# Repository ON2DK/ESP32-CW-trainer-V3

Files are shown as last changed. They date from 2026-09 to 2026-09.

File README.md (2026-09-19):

# ESP32 CW Trainer V3

Standalone ESP32-based CW/Morse trainer PCB for paddle and straight-key practice.

## V3 hardware revision

V3 standardizes the external connectors on real PCB-mounted parts instead of generic connector placeholders:

- **J4 DC input:** GCT DCJ200-10-A horizontal THT barrel jack
- **J10 Paddle:** CUI/Same Sky SJ1-3533NG 3.5 mm TRS jack
- **J11 Audio/headphone:** CUI/Same Sky SJ1-3533NG 3.5 mm TRS jack
- **J14 Straight Key:** CUI/Same Sky SJ1-3533NG 3.5 mm TRS jack

### Jack wiring

| Connector | Tip | Ring | Sleeve |
|---|---|---|---|
| J10 Paddle | DIT | DAH | GND |
| J11 Audio | Audio via 100 ohm | Audio via 100 ohm | GND |
| J14 Straight Key | STRAIGHT_KEY | Not connected | GND |

J4 uses pin 1 for the DC input to F1, pin 2 for GND, and pin 3 (internal switch contact) is intentionally unused.

## Main hardware

- ESP32-WROOM-32 / 38-pin DevKit footprint
- TFT interface
- Paddle input
- Straight-key input
- Rotary encoder with push switch
- LM386 audio amplifier
- Buzzer
- Volume control
- 12 V external input
- 500 mA resettable fuse
- TRACO TSR 1-2450 5 V regulator

## Design status

As of **19 September 2026**:

- KiCad: **10.0.4**
- ERC: **0 errors, 0 warnings**
- DRC: **0 violations**
- Unconnected PCB items: **0**
- Schematic parity problems: **0**
- Gerber production set regenerated after the V3 connector changes
- Hardware assembly/testing: **pending**

Two intentional ERC exceptions remain documented in the project: the project-specific ESP32 symbol/library difference and the GPIO34 input-only ADC check.

## Production files

The clean all-THT Gerber package contains:

- F.Cu / B.Cu
- F.Mask / B.Mask
- F.Silkscreen / B.Silkscreen
- Edge.Cuts
- PTH drill
- NPTH drill
- .gbrjob

Paste layers are not required for this THT board.

## Recommended repository files

- KiCad schematic (`.kicad_sch`)
- KiCad PCB (`.kicad_pcb`)
- KiCad project (`.kicad_pro`)
- Gerber ZIP
- Arduino firmware (`.ino`)
- Project logbook with BOM and photos
- PCB / schematic / 3D images

## Notes

Before ordering, inspect the final Gerbers in the PCB manufacturer's viewer, especially J4, J10, J11, J14, mounting holes and Edge.Cuts.

This project is currently electrically/design-rule checked, but the V3 hardware has not yet been validated on an assembled PCB.

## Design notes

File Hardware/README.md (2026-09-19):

# Hardware

Plaats hier de KiCad 10.0.4 projectbestanden van de ESP32 CW Trainer V3 (`.kicad_pro`, `.kicad_sch`, `.kicad_pcb`).

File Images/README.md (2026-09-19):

# Images

Afbeeldingen van schema, PCB, 3D-weergave en de later opgebouwde hardware.

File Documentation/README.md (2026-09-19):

# Documentation

Projectdocumentatie voor de ESP32 CW Trainer V3, waaronder het projectlogboek met BOM en foto's.

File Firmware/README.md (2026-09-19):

# Firmware

Plaats hier de Arduino IDE firmware (`.ino`) voor de ESP32 CW Trainer V3.

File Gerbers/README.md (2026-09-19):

# Gerbers

Plaats hier de definitieve productie-GERBER ZIP van de ESP32 CW Trainer V3.

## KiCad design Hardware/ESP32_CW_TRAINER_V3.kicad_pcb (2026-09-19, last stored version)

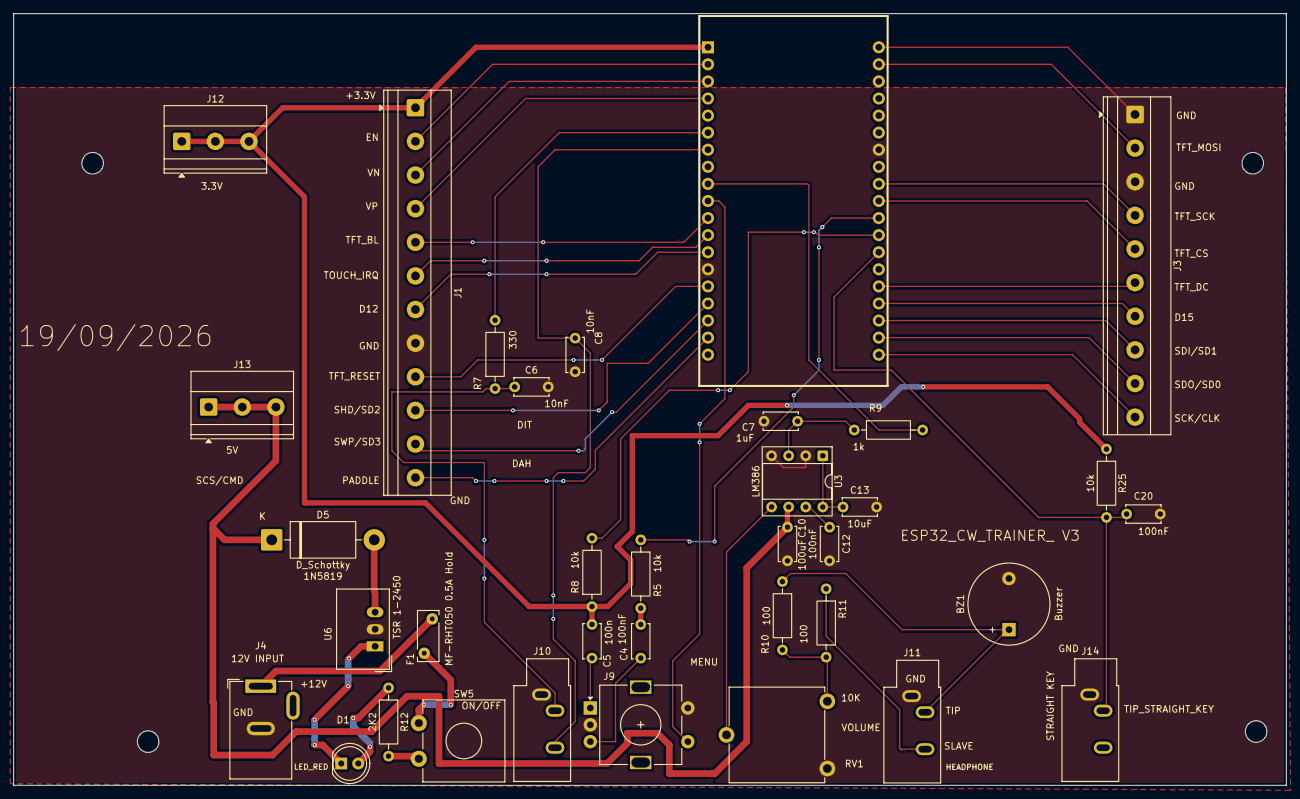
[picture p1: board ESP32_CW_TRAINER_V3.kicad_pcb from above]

Board: 2 copper layers, 189.2 x 114.8 mm, 35 parts (0 on the bottom side), 45 nets.

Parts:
BZ1: Buzzer; Buzzer_12x9.5RM7.6
C4, C12, C20: 100nF; C_Disc_D5.0mm_W2.5mm_P5.00mm
C5: 100n; C_Disc_D5.0mm_W2.5mm_P5.00mm
C6, C8: 10nF; C_Disc_D5.0mm_W2.5mm_P5.00mm
C7: 1uF; C_Disc_D5.0mm_W2.5mm_P5.00mm
C10: 100uF; C_Disc_D5.0mm_W2.5mm_P5.00mm
C13: 10uF; C_Disc_D5.0mm_W2.5mm_P5.00mm
D1: LED_RED; LED_D5.0mm
D5: D_Schottky; D_DO-201AD_P15.24mm_Horizontal
F1: MF-RHT050 0.5A Hold; Fuse_Bourns_MF-RHT050
J1: Conn_01x12; TerminalBlock_Phoenix_MKDS-1,5-12_1x12_P5.00mm_Horizontal
J3: Conn_01x10; TerminalBlock_Phoenix_MKDS-1,5-10_1x10_P5.00mm_Horizontal
J4: Barrel_Jack_Switch; BarrelJack_GCT_DCJ200-10-A_Horizontal
J9: RotaryEncoder_Switch; RotaryEncoder_Alps_EC11E-Switch_Vertical_H20mm
J10, J11, J14: AudioJack3; Jack_3.5mm_CUI_SJ1-3533NG_Horizontal
J12, J13: Conn_01x03; TerminalBlock_Phoenix_MKDS-1,5-3_1x03_P5.00mm_Horizontal
R5, R8, R25: 10k; R_Axial_DIN0207_L6.3mm_D2.5mm_P10.16mm_Horizontal
R7: 330; R_Axial_DIN0207_L6.3mm_D2.5mm_P10.16mm_Horizontal
R9: 1k; R_Axial_DIN0207_L6.3mm_D2.5mm_P10.16mm_Horizontal
R10, R11: 100; R_Axial_DIN0207_L6.3mm_D2.5mm_P10.16mm_Horizontal
R12: 2K2; R_Axial_DIN0207_L6.3mm_D2.5mm_P10.16mm_Horizontal
RV1: 10K; Potentiometer_ACP_CA14V-15_Vertical
SW5: POWER ON/OFF; SW_CW_GPTS203211B
U2: ESP32-WROOM-32; ESP32_DevKit_38P
U3: LM386; DIP-8_W7.62mm_Socket
U6: TSR 1-2450; Converter_DCDC_TRACO_TSR-1_THT

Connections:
+3.3V: C5.1, J1.1, J12.1, J12.2, J12.3, R8.1, R25.1, U2.2 (VDD)
+5V: C10.1, D5.1 (K), J13.1, J13.2, J13.3, U3.6 (V+)
/AUDIO: R9.2, U2.10 (IO25)
/D12: J1.7, U2.14 (IO12)
/D15: J3.7, U2.23 (IO15)
/DAH: C8.1, J10.R, U2.8 (IO32)
/DIT: R7.2, U2.7 (IO35)
/EN: J1.2, U2.3 (EN)
/ENC_A: R8.2, U2.27 (IO16)
/ENC_B: R5.1, U2.28 (IO17)
/ENC_SW: J9.S1, U2.11 (IO26)
/SCK/CLK: J3.10, U2.20 (SCK/CLK)
/SCS/CMD: J1.12, U2.19 (SCS/CMD)
/SDI/SD1: J3.8, U2.22 (SDI/SD1)
/SDO/SD0: J3.9, U2.21 (SDO/SD0)
/SHD/SD2: J1.10, U2.17 (SHD/SD2)
/STRAIGHT_KEY: C20.1, J14.T, R25.2, U2.26 (IO4)
/SWP/SD3: J1.11, U2.18 (SWP/SD3)
/TFT_BL: J1.5, U2.12 (IO27)
/TFT_CS: J3.5, U2.29 (IO5)
/TFT_DC: J3.6, U2.24 (IO2)
/TFT_MOSI: J3.2, U2.37 (IO23)
/TFT_RESET: J1.9, U2.16 (IO13)
/TFT_SCK: J3.4, U2.30 (IO18)
/TOUCH_IRQ: J1.6, U2.13 (IO14)
/VN: J1.3, U2.4 (SENSOR_VP)
/VP: J1.4, U2.5 (SENSOR_VN)
GND: BZ1.2 (-), C6.2, C7.1, C8.2, C10.2, C12.2, C13.2, C20.2, J1.8, J3.1, J3.3, J4.2, J9.C, J9.S2, J10.S, J11.S, J14.S, RV1.3, U2.1 (GND), U2.15 (GND), U2.38 (GND), U3.2 (-), U3.4 (GND), U6.2 (GND)
unnamed: BZ1.1 (+), J11.T, R10.1
unnamed: C4.1, R5.2
unnamed: C4.2, J9.B
unnamed: C5.2, J9.A
unnamed: C6.1, J10.T, R7.1
unnamed: C13.1, U3.1 (GAIN), U3.8 (GAIN)
unnamed: D1.2 (A), R12.1
unnamed: D1.1 (K), U6.1 (IN)
unnamed: D5.2 (A), U6.3 (OUT)
unnamed: F1.2, J4.1
unnamed: J11.R, R11.1
unnamed: R10.2, R11.2, RV1.1
unnamed: RV1.2, U3.5
unnamed: F1.1, SW5.1 (A)
unnamed: R12.2, SW5.2 (B)
unnamed: C7.2, R9.1, U3.3 (+)
unnamed: C12.1, U3.7 (BYPASS)

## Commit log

2026-09-19 Document ESP32 CW Trainer V3 hardware revision
2026-09-19 Add Gerbers folder
